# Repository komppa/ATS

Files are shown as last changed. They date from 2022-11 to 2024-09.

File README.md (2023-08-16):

# ATS - Automatic Transfer Switch





Intelligent power switching between two power sources. Feed load from both grid and generator without manual hassle!

## Install

Automatic transfer switch requires following to be installed
- python3
- pip3
- platformio

Platfrmio can be installed by using pip
```bash
pip3 install -U platformio
```

After that you can install dependencies of the project
```bash
pio lib install
```

## Running tests

Tests are allowed to be executed only for the native environment that does not require real hardware to be connected to the tester.
Run tests by executing the following command
```bash
pio test -e native
```

## Building

Since platformio.ini includes two environmets (native & megaatmega2560 for Arduino Mega) you need to specify for which target you want to build project. To build for ATmega2560:
```bash
pio run -e megaatmega2560
```

Note that before building, pio launches pre python script that takes version of the project from VERSION file on root folder and defines that as definition that we'll use on our code.

## Running on simulator

The ATS repository root includes two essential files: diagram.json and wokwi.toml. These files enable you to run the project using the Wokwi simulator. To proceed:

1. Compile the project specifically for the megaatmega2560 configuration.

2. Launch the Wokwi simulator. If you are using the PlatformIO, the simulator will automatically detect the location of the executable. However, ensure that you do not compile for the 'native' environment as specified in platformio.ini.

<br />
<div>
    
</div>
<br />

### Simulator Components and Their Real-World Equivalents

Within the simulator, every essential component found in the real hardware is mirrored to provide an authentic experience including display, keypad, buzzer, LEDs and switches. 

**LED is as follows:**

Left LED: When illuminated, it indicates that the grid is being utilized to power the load

Right LED: If this LED is ON, it signifies that the generator (or genset) is being used, and the contactor is activated

**Switches: There are two switches in the simulator to indicate whether the grid and/or generator is delivering 250V to the system**

Note: In the real-world hardware, we employ voltage sensors to detect and display the exact voltage levels. However, since these sensors don't exist in our simulator, we've implemented these two switches as a substitute. These switches are binary, representing either 0V or 250V. This means we're assuming a voltage difference between 0 and 250V based solely on the switch's position. On actual hardware, the precise voltage is displayed thanks to the real voltage sensors

## Sketch about the idea / FSM

<br />
<div>
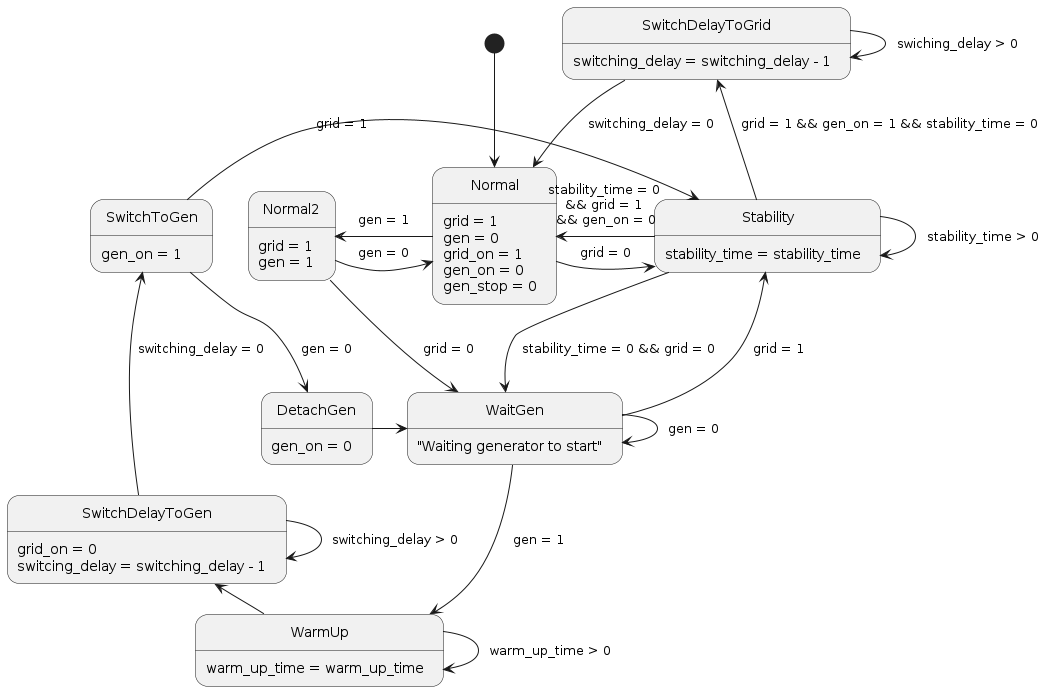
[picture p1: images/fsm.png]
    
<div/>
<br />

## TODO

- Calibrate each voltage sensors separately from settings tab
- JUnit CI does not get real test results (only whether those fail or not)
- Beeper when button pressed
- When exiting settigns and going back in, vertical index of display variable breaks

🔌🏠🔌<br />
**Happy switching!**

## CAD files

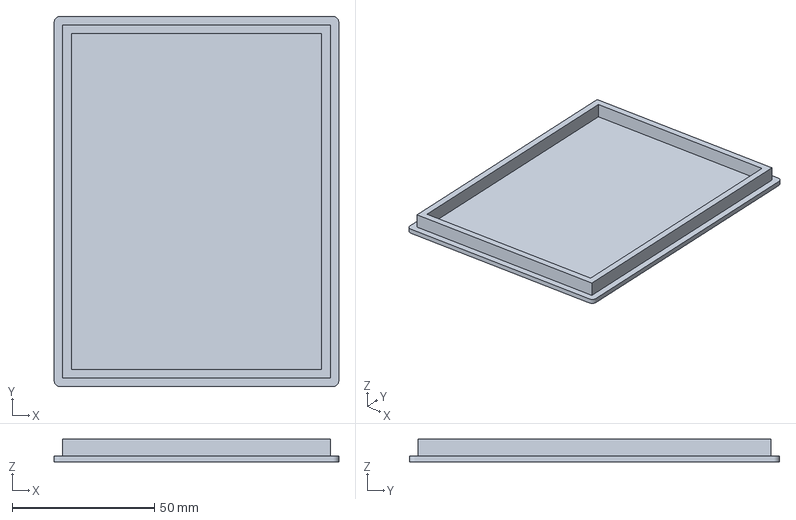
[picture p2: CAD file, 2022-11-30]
3d/base.3mf
100.0 x 130.0 x 8.00 mm

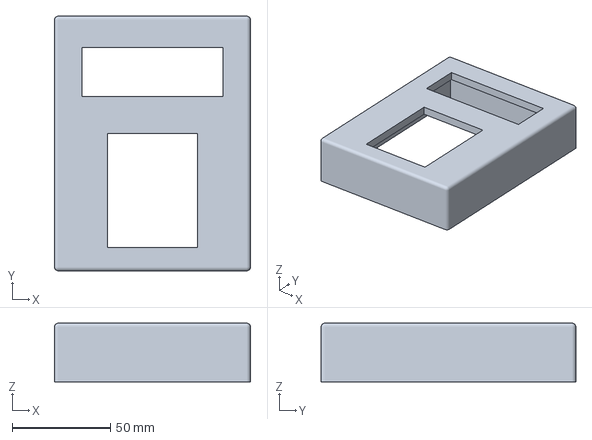
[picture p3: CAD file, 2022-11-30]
3d/case.3mf
100.0 x 130.0 x 30.0 mm

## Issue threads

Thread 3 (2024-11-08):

Replace voltage sensors with APC UPS line fail signal

komppa, 2024-11-08:
APC UPS serial port can provide "line fail signal". Use it to define whether the grid is up or not

komppa, 2024-11-08:
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

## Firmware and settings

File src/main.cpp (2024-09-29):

/**
   Automatic Transfer Switch

   Copyright (C) 2020, Konsta Rantakangas.
   Released under the MIT License.
*/
#ifndef UNIT_TEST
#include <LiquidCrystal.h>
#include <Keypad.h>
#include <Arduino.h>
#include "writer.h"
#include "hardware.h"
#include <stdio.h>
#include "FiniteStateMachine.hpp"   // for Deps
#include "display.h"
#include "settings.h"
#include "logger.h"
#include "sound.h"


// Display contacts: VSS=GND, VDD=5V, RW=GND, A=5V(VIA 220OHM RESISTOR), K=GND 
//                RS, E , D4,D5,D6,D7
LiquidCrystal lcd(12, 11, 10, 9, 8, 7);

const byte KEYPAD_ROWS = 4;
const byte KEYPAD_COLS = 3;
byte rowPins[KEYPAD_ROWS] = {5, 4, 3, 2};
byte colPins[KEYPAD_COLS] = {A3, A2, A1};
char keys[KEYPAD_ROWS][KEYPAD_COLS] = {
    {'1', '2', '3'},
    {'4', '5', '6'},
    {'7', '8', '9'},
    {'*', '0', '#'}
};

Keypad keypad = Keypad(makeKeymap(keys), rowPins, colPins, KEYPAD_ROWS, KEYPAD_COLS);
Writer writer = Writer(&lcd);

Hardware hardware;
Timer timer(&hardware);
Settings settings;
Logger logger(&hardware);

Deps ATSFSMDeps = {
    .hardware = &hardware,
    .timer = &timer,
    .keypad = &keypad,
    .writer = &writer
};

extern State UnknownStart;
FSM sm = FSM(UnknownStart, &ATSFSMDeps);

Deps displayFSMDeps = {
    .hardware = &hardware,
    .timer = &timer,
    .keypad = &keypad,
    .writer = &writer,
    .sm = &sm,
    .settings = &settings
};

extern State DisplayUnknownStart;
FSM display = FSM(DisplayUnknownStart, &displayFSMDeps);

byte generator_icon[8] = {B00000, B11111, B10011, B11111, B10101, B11111, B10011};
byte load_icon[8] = {B00000, B00100, B01110, B11111, B11111, B11011, B11011};
byte grid_icon[8] = {B10001, B11111, B10001, B10001, B10001, B10001, B10001, B10001};


void setup() {

    Serial.begin(115200);

    LOG(INFO, "===============================");
    LOG(INFO, " ATS - Automatic Transfer Switch");
    LOG(INFO, "       Version: " SW_VERSION);
    LOG(INFO, "   Booting Up... Please Wait.");
    LOG(INFO, "    Crafted with precision by");
    LOG(INFO, "    Komppa (github.com/komppa)");
    LOG(INFO, "===============================");
    LOG(INFO, "");

    LOG(DEBUG, "Initializing LCD");
    lcd.begin(DISPLAY_WIDTH, 2);
    LOG(DEBUG, "Initialized LCD");

    lcd.createChar(ICON_GRID, grid_icon);
    lcd.createChar(ICON_GENERATOR, generator_icon);
    lcd.createChar(ICON_LOAD, load_icon);

    lcd.clear();
    lcd.setCursor(0, 0);

    writer.setMode(RAW);

    // For checking whether this is simulator in runtime
    pinMode(PIN_IS_SIMULATOR, INPUT_PULLUP);

    pinMode(PIN_CONTACTOR_GRID, OUTPUT);
    pinMode(PIN_CONTACTOR_GENERATOR, OUTPUT);

    pinMode(PIN_VOLTAGE_GRID, INPUT_PULLUP);
    pinMode(PIN_VOLTAGE_GENERATOR, INPUT_PULLUP);

    // Buzzer
    pinMode(PIN_BUZZER, OUTPUT);

    // Init EEPROM
    LOG(DEBUG, "Initializing HW EEPROM");
    hardware.initEEPROM();
    LOG(DEBUG, "Initialized EEPROM & loading settings");

    // Get values from EEPROM at startup
    settings.load(&hardware, &timer);
    LOG(DEBUG, "Loaded settings from EEPROM");

    // Play a starup sound
    // startup_sound();

    // Wait a little bit for hardware to settle
    delay(500);

}


void loop() {

    // Limiter
    delay(100);

    // Regular updates
    timer.update();
    writer.update();
    if (millis() > 1000) {
        sm.update();
        display.update();
    }
}


#endif // Do not compile setup and loop if unit testing

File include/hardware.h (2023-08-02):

#ifndef HARDWARE_H
#define HARDWARE_H

#include <stdint.h>
#include "ZMPT101B.h"

// If building release for Arduino, include it to be used by this class
#ifdef UNIT_TEST
#include "gmock/gmock.h"
#else
#include <Arduino.h>
#endif


#define UNKNOWN -1
#define MOCK_VOLTAGE(pin, ret_val) (ON_CALL(hardware, getVoltageAC(pin)).WillByDefault(Return(ret_val)))

#define MOCK_MILLIS(ret_val) (ON_CALL(hardware, time()).WillByDefault(Return(ret_val)))
#define MOCK_FAST_MILLIS(timer, ff_val)                        \
    for (int i = 1; i <= ff_val; i++) {                             \
        if (i % 1000 == 0) {                                        \
            ON_CALL(hardware, time()).WillByDefault(Return(i));   \
            timer.update();                                         \
        }                                                           \
    }

// Pin definitions
// Contactors
#define PIN_CONTACTOR_GRID      22  // @2560
#define PIN_CONTACTOR_GENERATOR 23  // @2560
// Voltage meas modules
#define PIN_VOLTAGE_GRID        67  // A13 @2560
#define PIN_VOLTAGE_GENERATOR   68  // A14 @2560
#define PIN_VOLTAGE_LOAD        69  // A15 @2560
// Buzzer
#define PIN_BUZZER              21
// Keypad
#define PIN_KEYPAD_ROW_1        5
#define PIN_KEYPAD_ROW_2        4
#define PIN_KEYPAD_ROW_3        3
#define PIN_KEYPAD_ROW_4        2
#define PIN_KEYPAD_COLUMN_1     17  // A3
#define PIN_KEYPAD_COLUMN_2     16  // A2
#define PIN_KEYPAD_COLUMN_3     15  // A1
// Display
#define PIN_DISPLAY_RS          12
#define PIN_DISPLAY_E           11
#define PIN_DISPLAY_D4          10
#define PIN_DISPLAY_D3          9
#define PIN_DISPLAY_D2          8
#define PIN_DISPLAY_D1          7
// Simulator runtime check
#define PIN_IS_SIMULATOR        53

// EEPROM addresses
static const int EEPROM_INITIALIZED =           42;
static const int EEPROM_INIT_ADDRESS =          568;    // Random address

#define EEPROM_ADDRESS_SOURCE                   0       // Left some space for future between 0 and 10
#define EEPROM_ADDRESS_STABILITY_TIME           10      // Currently uint_8 saved here but there is space for future uint_16
#define EEPROM_ADDRESS_WARM_UP_TIME             12
#define EEPROM_ADDRESS_SWITCHING_DELAY_TIME     14

#define EEPROM_ADDRESS_GRID_ZERO_VOLTAGE_POINT  16
#define EEPROM_ADDRESS_GRID_KNOWN_VOLTAGE_POINT 18
#define EEPROM_ADDRESS_GENERATOR_ZERO_VOLTAGE_POINT 20
#define EEPROM_ADDRESS_GENERATOR_KNOWN_VOLTAGE_POINT 22
#define EEPROM_ADDRESS_LOAD_ZERO_VOLTAGE_POINT  24
#define EEPROM_ADDRESS_LOAD_KNOWN_VOLTAGE_POINT 26



class Hardware {
    private:
        int my_var;
        // For voltage sensors
        #ifndef UNIT_TEST
        ZMPT101B z_grid;
        ZMPT101B z_generator;
        ZMPT101B z_load;
        #endif
    public:
        Hardware();
        // Arduino ones
        virtual unsigned long time();
        virtual void setDigital(uint8_t pin, uint8_t val);
        virtual int getDigital(uint8_t pin);
        virtual void wait(unsigned long ms);
        // Voltage sensor to be able to mocked
        virtual int getVoltageAC(uint8_t pin);
        virtual int calibrateKnownVoltage(uint8_t pin, uint16_t knownVoltage);
    	virtual int calibrateZeroVoltage(uint8_t pin);
        virtual bool isSimulator();
        // TODO mocs for eeprom
        virtual int initEEPROM();
        virtual int eepromRead(int address);
        virtual int eepromWrite(int address, int value);
};

#ifdef UNIT_TEST
class MockHardware: public Hardware {
    public:
        // Arduino
        MOCK_METHOD(unsigned long, time, ());
        MOCK_METHOD(void, setDigital, (uint8_t, uint8_t));
        MOCK_METHOD(int, getDigital, (uint8_t));
        MOCK_METHOD(void, wait, (unsigned long));
        // Voltage sensor
        MOCK_METHOD(int, getVoltageAC, (uint8_t));
};
#endif  // UNIT_TEST

#endif

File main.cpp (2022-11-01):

// #include "FiniteStateMachine.hpp"
// #include "states.h"
// #include <stdio.h>
// #include <unistd.h>


// extern FSM sm;
// extern Timer timer;


// int main() {


//     timer.reset_timer(ALL);

//     while(1) {
//         timer.update(); // Timer
//         sm.update();    // State machine
//     }

// }

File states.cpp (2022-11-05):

#include "states.h"
#include <stdio.h>
#include "hardware.h"


Timer timer;


State UnknownStart = State(enterUnknownStart, updateUnknownStart, exitUnknownStart);
State Normal = State(enterNormal, updateNormal, exitNormal);
State Stability = State(enterStability, updateStability, exitStability);
State WaitGen = State(enterWaitGen, updateWaitGen, exitWaitGen);
State WarmUp = State(enterWarmUp, updateWarmUp, exitWarmUp);
State SwitchDelayToGen = State(enterSwitchDelayToGen, updateSwitchDelayToGen, exitSwitchDelayToGen);
State SwitchToGen = State(enterSwitchToGen, updateSwitchToGen, exitSwitchToGen);
State DetachGen = State(enterDetachGen, updateDetachGen, exitDetachGen);
State Normal2 = State(enterNormal2, updateNormal2, exitNormal2);
State SwitchDelayToGrid = State(enterSwitchDelayToGrid, updateSwitchDelayToGrid, exitSwitchDelayToGrid);


FSM sm = FSM(UnknownStart);
Hardware hardware;


bool is_grid_up() {
    // TODO analogRead bc of voltage module
    // return hardware.digitalRead(PIN_CONTACTOR_GRID);
}

bool is_generator_up() {
    // TODO analogRead bc of voltage module
    // return hardware.digitalRead(PIN_CONTACTOR_GENERATOR);
}

void set_grid_contactor(bool status) {
    // It is so critical action to ensure that the other contactor is off when
    // switching grid on, that other contactor is switched off before grid is kicked in

    // Grid is being activated, switch generator off before that
    if (status == true) {
        hardware.digitalWrite(PIN_CONTACTOR_GENERATOR, false);
        delay(100);
    }

    hardware.digitalWrite(PIN_CONTACTOR_GRID, status);
}

void set_generator_contactor(bool status) {
    // Generator is being activated, switch grid off before that
    // and do a little guard wait
    if (status == true) {
        hardware.digitalWrite(PIN_CONTACTOR_GRID, false);
        delay(100);
    }

    hardware.digitalWrite(PIN_CONTACTOR_GENERATOR, status);
}


/**
 * UNKNOWNSTART -STATE
 * When defvice starts. We do not know what the state of the ATS
 * is when the Arduino starts. Find it and push state machine to
 * follow real switching board.  
*/
// This 'UNKNOWN_START'-state is used as a setup. 
// This is why timers are reseted here
void enterUnknownStart() {
    // TODO CRIT TODO HIGH check really and not just forward a call
    timer.reset_timer(ALL);
    sm.transitionTo(Normal);
}

void updateUnknownStart() {
    printf("@updateUnknownStart\n");

}

void exitUnknownStart() {
    printf("@exitUnknownStart\n");

}


/**
 * NORMAL -STATE
 * 
*/
void enterNormal() {

    printf("@enterNormal\n");

    // Init contactor states 
    set_generator_contactor(false);
    set_grid_contactor(true);
    // TODO LOW gen_stop

}

void updateNormal() {


    // Did grid went down?
    if (is_grid_up() == false) {
        sm.transitionTo(Stability);
    }

    // Did generator start even if grid is up?
    if (is_generator_up() == true) {
        sm.transitionTo(Normal2);
    }

}

void exitNormal() {

}


/**
 * STABILITY -STATE
 * 
*/
void enterStability() {
    // Reset stability time
    timer.reset_timer(STABILITY_TIME);
    // Start counting stability time from the start
    timer.set_timer(STABILITY_TIME, true);
}

void updateStability() {

    // Stability time counted all down to zero and grid still is not up
    if (timer.get_timer_time(STABILITY_TIME) == 0 && is_grid_up() == false) {
        sm.transitionTo(WaitGen);
    }

    if (
        timer.get_timer_time(STABILITY_TIME) == 0 &&
        is_grid_up() == true &&
        is_generator_up() == false
    ) {
        sm.transitionTo(Normal);
    }

    if (
        is_grid_up() == true &&
        is_generator_up() == true &&
        timer.get_timer_time(STABILITY_TIME) == 0
    ) {
        sm.transitionTo(SwitchDelayToGrid);
    }

}

void exitStability() {
    timer.set_timer(STABILITY_TIME, false);
}


/**
 * WAITGEN -STATE
 * 
*/
void enterWaitGen() {

}

void updateWaitGen() {

    // Do not wait that the generator starts since
    // grid went back online
    if (is_grid_up() == true) {
        sm.transitionTo(Stability);
    }

    if (is_generator_up() == true) {
        sm.transitionTo(WarmUp);
    }

}

void exitWaitGen() {

}


/**
 * WARMUP -STATE
 * 
*/
void enterWarmUp() {
    timer.reset_timer(WARM_UP_TIME);
    timer.set_timer(WARM_UP_TIME, true);
}

void updateWarmUp() {
    if (timer.get_timer_time(WARM_UP_TIME) == 0) {
        sm.transitionTo(SwitchDelayToGen);
    }
}

void exitWarmUp() {
    timer.set_timer(WARM_UP_TIME, false);
}


/**
 * SWITCHDELAYTOGEN -STATE
 * 
*/
void enterSwitchDelayToGen() {
    // Disconnect grid contactor
    set_grid_contactor(false);
    // Set timers
    timer.reset_timer(SWITCHING_DELAY);
    timer.set_timer(SWITCHING_DELAY, true);

}

void updateSwitchDelayToGen() {

    if (timer.get_timer_time(SWITCHING_DELAY) == 0) {
        sm.transitionTo(SwitchToGen);
    }

}

void exitSwitchDelayToGen() {
    timer.set_timer(SWITCHING_DELAY, false);
}


/**
 * SWITCHTOGEN -STATE
 * 
*/
void enterSwitchToGen() {

    // Connect generator to load
    set_generator_contactor(true);

    // This state is not fully implemented as specification suggests.
    // Specification is too inaccurate. >We assume that the generator keeps running
    sm.transitionTo(Stability);

}

void updateSwitchToGen() {
    // Not used, check is made instanly on @enter
}

void exitSwitchToGen() {

}


/**
 * DETACHGEN -STATE
 * 
*/
void enterDetachGen() {
    // Not used.
    // But if someone uses, kick instantly to next (only one possible next) state
    sm.transitionTo(WaitGen);
}

void updateDetachGen() {

}

void exitDetachGen() {

}


/**
 * NORMAL2 -STATE
 * 
*/
void enterNormal2() {

}

void updateNormal2() {

    if (is_generator_up() == false) {
        sm.transitionTo(Normal);
    }

    if (is_grid_up() == false) {
        sm.transitionTo(WaitGen);
    }

}

void exitNormal2() {

}


/**
 * SWITCHDELAYTOGRID -STATE
 * 
*/
void enterSwitchDelayToGrid() {
    timer.reset_timer(SWITCHING_DELAY);
    timer.set_timer(SWITCHING_DELAY, true);
}

void updateSwitchDelayToGrid() {

    if (
        is_grid_up() == true &&
        is_generator_up() == true &&
        timer.get_timer_time(STABILITY_TIME) == 0
    ) {
        sm.transitionTo(Normal);
    }

}

void exitSwitchDelayToGrid() {
    timer.set_timer(SWITCHING_DELAY, false);
}

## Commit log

2022-11-01 Test framework changed to be GoogleTest
2022-11-02 Tests for timer reset
2022-11-03 Test runner and tests for timer
2022-11-05 Fixed build issues and added voltage sensor support
    [ZMPT101B.cpp, hardware.cpp, hardware.h]
2022-11-06 Mockable delay and voltage sensor support
2022-11-30 add 3D printable cover and base for control unit
    [base.3mf, case.3mf]
2022-12-01 implement fast forward millis timer mock
2022-12-23 fix states to match sm arg
    [states.cpp]
2022-12-23 implement test to test ATS states by mocking grid voltage
2022-12-27 fix update of switchtogen state
    [states.cpp]
2022-12-28 display fsm and a lot of bug fixes
    [hardware.cpp, hardware.h, main.cpp]
2023-01-01 writer padding if dynvar shorter than its space
    [main.cpp]
2023-01-07 commit input from display to timer class
2023-03-09 fix circular states enum dep
    [main.cpp]
2023-06-19 Remove incorrect stability and warmup time from main
    [main.cpp]
2023-06-19 Softreset wire & override to settings
2023-06-22 implement timer stability time change from settings
    [hardware.h, main.cpp, states.cpp]
2023-06-26 bug fix: state stability to switchdelaytogrid and reset timer all
    [states.cpp]
2023-06-26 logger to class and logger test case use possibility
2023-07-03 state decls and hw methods for voltage sensor cal
2023-07-04 implement possibility to perform raw calibration from settings
2023-07-04 fix tests by removing zmpt sensor when testing
    [hardware.cpp, hardware.h]
2023-07-04 Release ATS 1.3 - simply voltage sensor calibration from settings
2023-08-02 add buzzer and startup sound
    [hardware.h, main.cpp]
2024-09-28 implement fixed tab length calc for logger
    [logger.cpp]
2024-09-28 remove print from hardware lib and add init commit for timers
2024-09-28 simulator: initial grid switch value to be grid online
2024-11-08 disable voltage sensor calibration setting options
